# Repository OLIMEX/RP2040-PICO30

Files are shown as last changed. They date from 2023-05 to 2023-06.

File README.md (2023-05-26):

# RP2040-PICO30

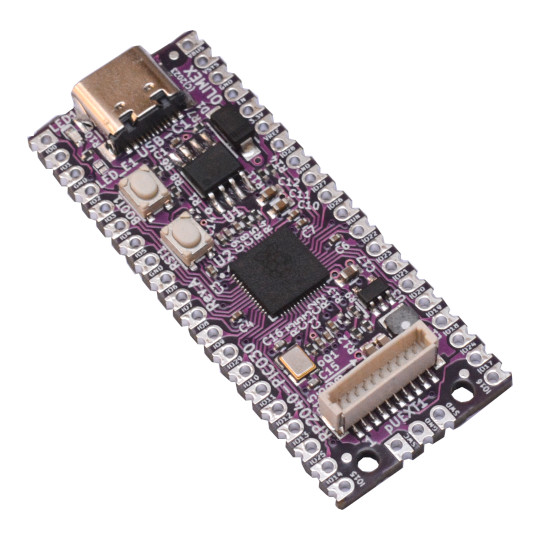
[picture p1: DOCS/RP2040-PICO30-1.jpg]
RP2040-PICO30-1


RP2040-PICO30 is Open Source Harrdware re-design of original RP2040-PICO from Rqaspberry Pi 

## Features

* RP2040 CortexM0 microcontroller
* RP2040-PICO pinout and dimentions
* SY8089A 3.3V 2A (3A peak) DCDC power supply
* 30 GPIOs available to the user
* USB-C High Speed USB 2.0 connector for powering the board and communication
* Boot button
* RESET button
* 2MB or 16MB Flash
* Optional UEXT connector (U version)
* Optional status LED (U version)
* Dimensions 51 x 21 mm

Product page: https://www.olimex.com/Products/MicroPython/RP2040-PICO30/open-source-hardware

## Licenses

* Hardware is released under CERN Open Hardware Licence Version 2 - Strongly Reciprocal, all silkscreen credits to Olimex should remain;
* Software is released under GPL3 Licensee
* Documentation is released under CC BY-SA 3.0

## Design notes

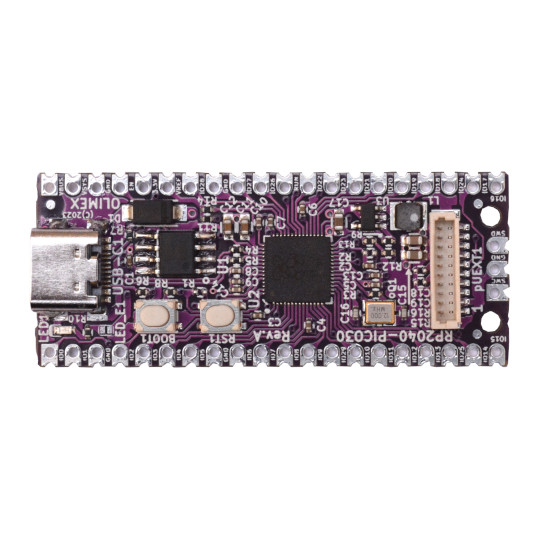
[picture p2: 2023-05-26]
DOCS/RP2040-PICO30-2.jpg

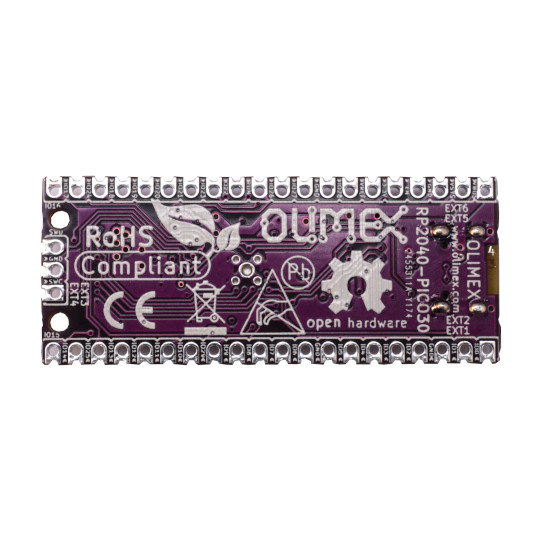
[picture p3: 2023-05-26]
DOCS/RP2040-PICO30-3.jpg

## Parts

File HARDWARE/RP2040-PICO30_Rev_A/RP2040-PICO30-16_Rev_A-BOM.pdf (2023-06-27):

# RP2040-PICO30-16_Rev_A-BOM 06/27/2023

Quantity | Designation | Package | Designator
1 | 1.3R/1%/R0402 | R0402 | R14
2 | 27R/R0402 | R0402 | R4,R5
2 | 100R/R0402 | R0402 | R3,R8
1 | 200R/1%/R0402 | R0402 | R11
2 | 5.1k/R0402 | R0402 | R6,R7
1 | 10k/R0402 | R0402 | R1
1 | 49.9k/1%/R0402 | R0402 | R13
1 | 220k/R0402 | R0402 | R12
1 | 1M/R0402 | R0402 | R9
1 | 2.2uH/1.5A/DCR=58mR/20% /3.00x3.00x1.50mm/ CD32(NRS3015T2R2MNGH) | CD32 | L1
2 | 27pF/50V/5%/C0G/C0402 | C0402 | C15,C16
12 | 100nF/10V/10%/X7R/C0402 | C0402 | C1,C2,C3,C4,C5, C6,C7,C8,C9, C10,C13,C14
2 | 1uF/10V/20%/X5R/C0603 | C0603 | C11,C12
3 | 22uF/6.3V/20%/X5R/C0603 | C0603 | C17,C18,C19
1 | 1N5822/SS34/SMA | SMA | D1
1 | W25Q128JVSIQ(SOIC-8_208mils) | SO-8_208mil | U1
1 | RP2040(QFN-56_7x7mm_P0.4mm) | QFN56 | U2
1 | SY8089AAAC(SOT23-5) | SOT-23-5 | U3
1 | Q12MHz/20pF/10ppm/4P/3.2x2.5mm | TSX-3.2x2.5mm | Q1
2 | YTS-A016-X | YTS-A016-X | BOOT1,RST1
1 | USB-C-16P-F (A40-00119-A52-12) | USB2.0_TYPE-C (A40-00119-A52-12) | USB-C1
1 | Opened | SJ_1_SMALLER | LED_E1
3 | NA(2.2k/R0402) | R0402 | R10,R15,R16
1 | NA(10k/R0402) | R0402 | R2
1 | NA(LED/GREEN/0603) | LED_0603 | LED1
1 | NA(SH1.0-10P-180D) | BM10B-SRSS-TB | pUEXT1
2 | NA(HN1x3) | HN1x3 | EXT3,EXT4
4 | NA(HN1x20) | HN1x20 | EXT1,EXT2, EXT5,EXT6

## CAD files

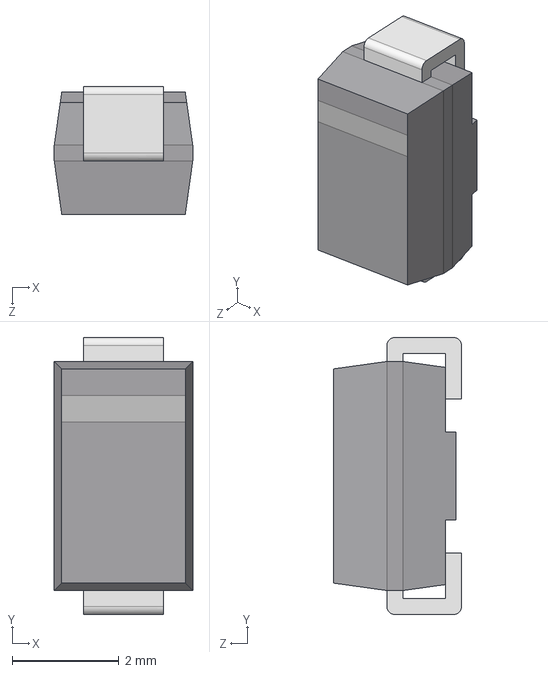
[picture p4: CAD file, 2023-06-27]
HARDWARE/RP2040-PICO30_Rev_A/3d/DO-214AC_SMA.step
2.60 x 5.20 x 2.40 mm

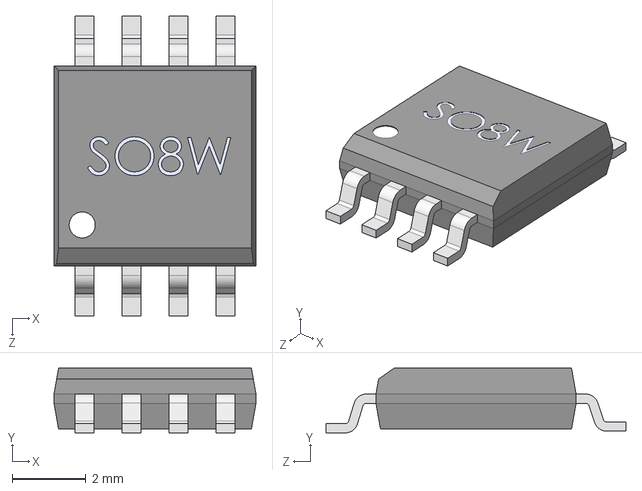
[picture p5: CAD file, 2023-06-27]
HARDWARE/RP2040-PICO30_Rev_A/3d/SO-8_208mil---SOIC8_Wide_5mmx5mm.step
5.46 x 1.75 x 8.10 mm

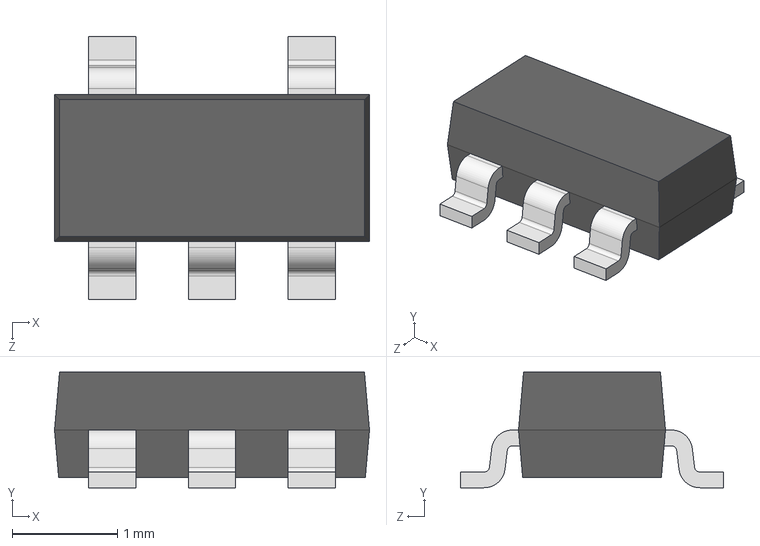
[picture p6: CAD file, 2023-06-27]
HARDWARE/RP2040-PICO30_Rev_A/3d/SOT-23-5.step
3.00 x 1.10 x 2.50 mm

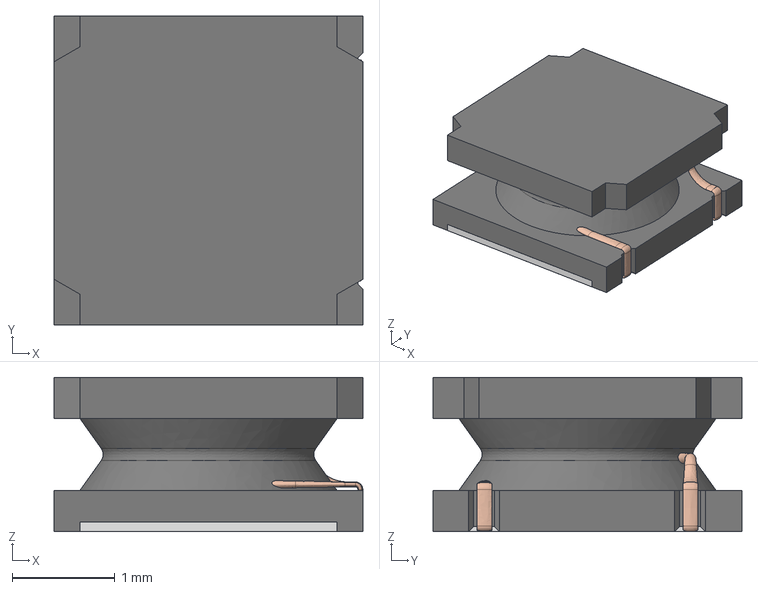
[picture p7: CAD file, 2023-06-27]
HARDWARE/RP2040-PICO30_Rev_A/3d/L-CD32_shielded.step
3.00 x 3.00 x 1.50 mm

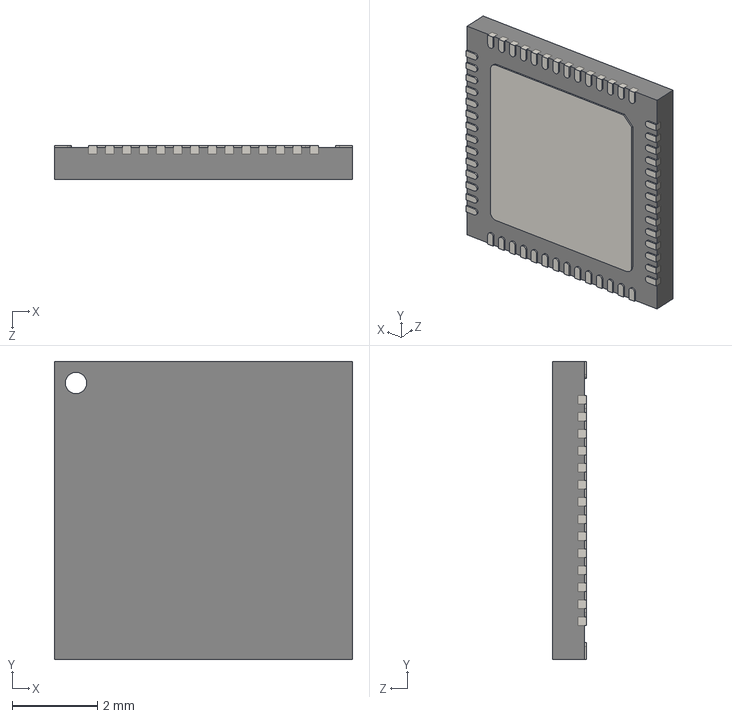
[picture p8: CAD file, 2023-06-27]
HARDWARE/RP2040-PICO30_Rev_A/3d/QFN56_0_4.step
7.00 x 7.00 x 0.8 mm

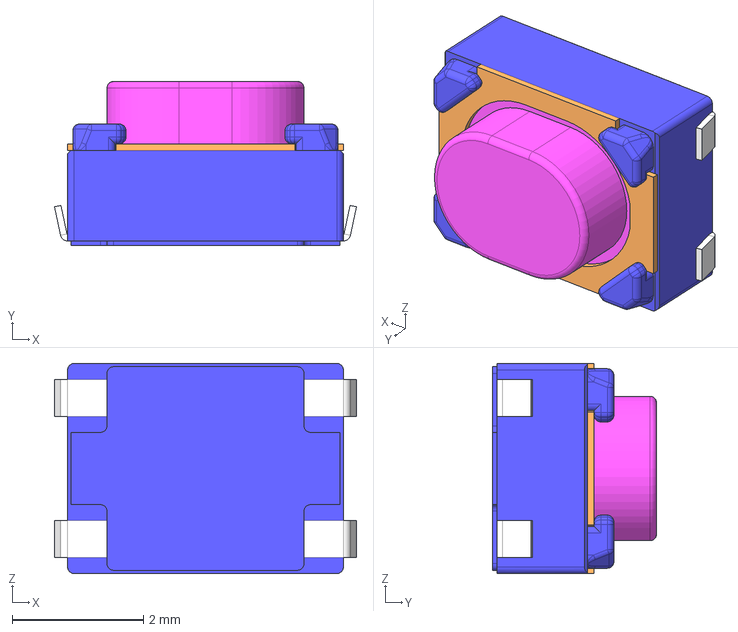
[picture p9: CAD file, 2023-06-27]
HARDWARE/RP2040-PICO30_Rev_A/3d/YTS-A016-X(SKRPABE010).stp
4.60 x 2.50 x 3.20 mm

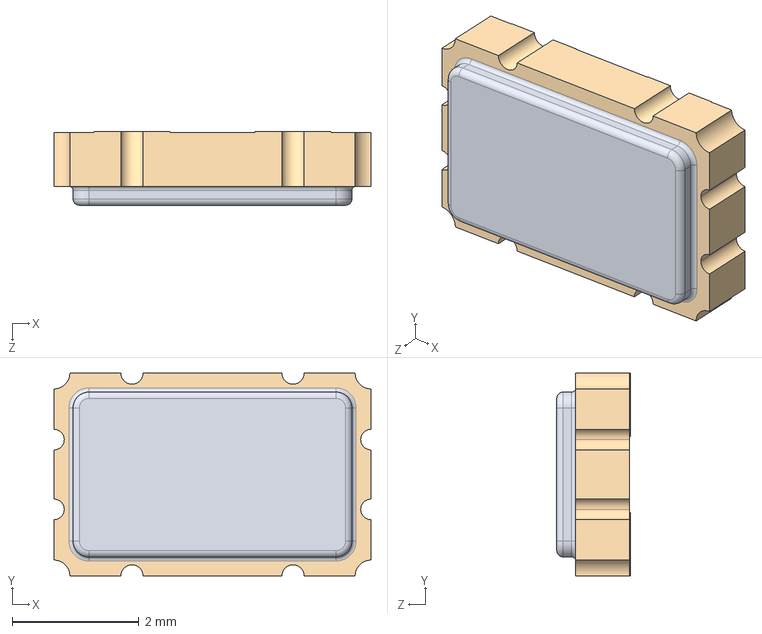
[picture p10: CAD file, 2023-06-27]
HARDWARE/RP2040-PICO30_Rev_A/3d/QSG5032.step
5.00 x 3.20 x 1.16 mm

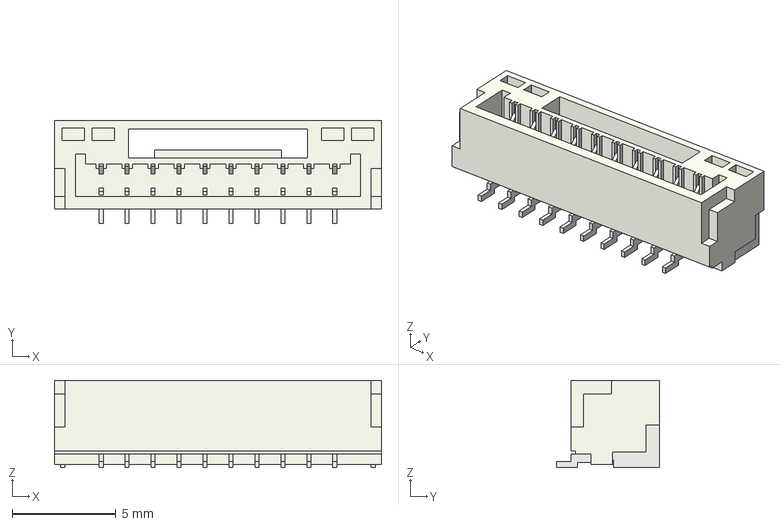
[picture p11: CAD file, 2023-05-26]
HARDWARE/RP2040-PICO30_Rev_A/3d/BM10B-SRSS-TB(JST_GH_BM10B-GHS-TBT_1x10-1MP_P1.25mm_Vertical).step
15.8 x 4.95 x 4.20 mm

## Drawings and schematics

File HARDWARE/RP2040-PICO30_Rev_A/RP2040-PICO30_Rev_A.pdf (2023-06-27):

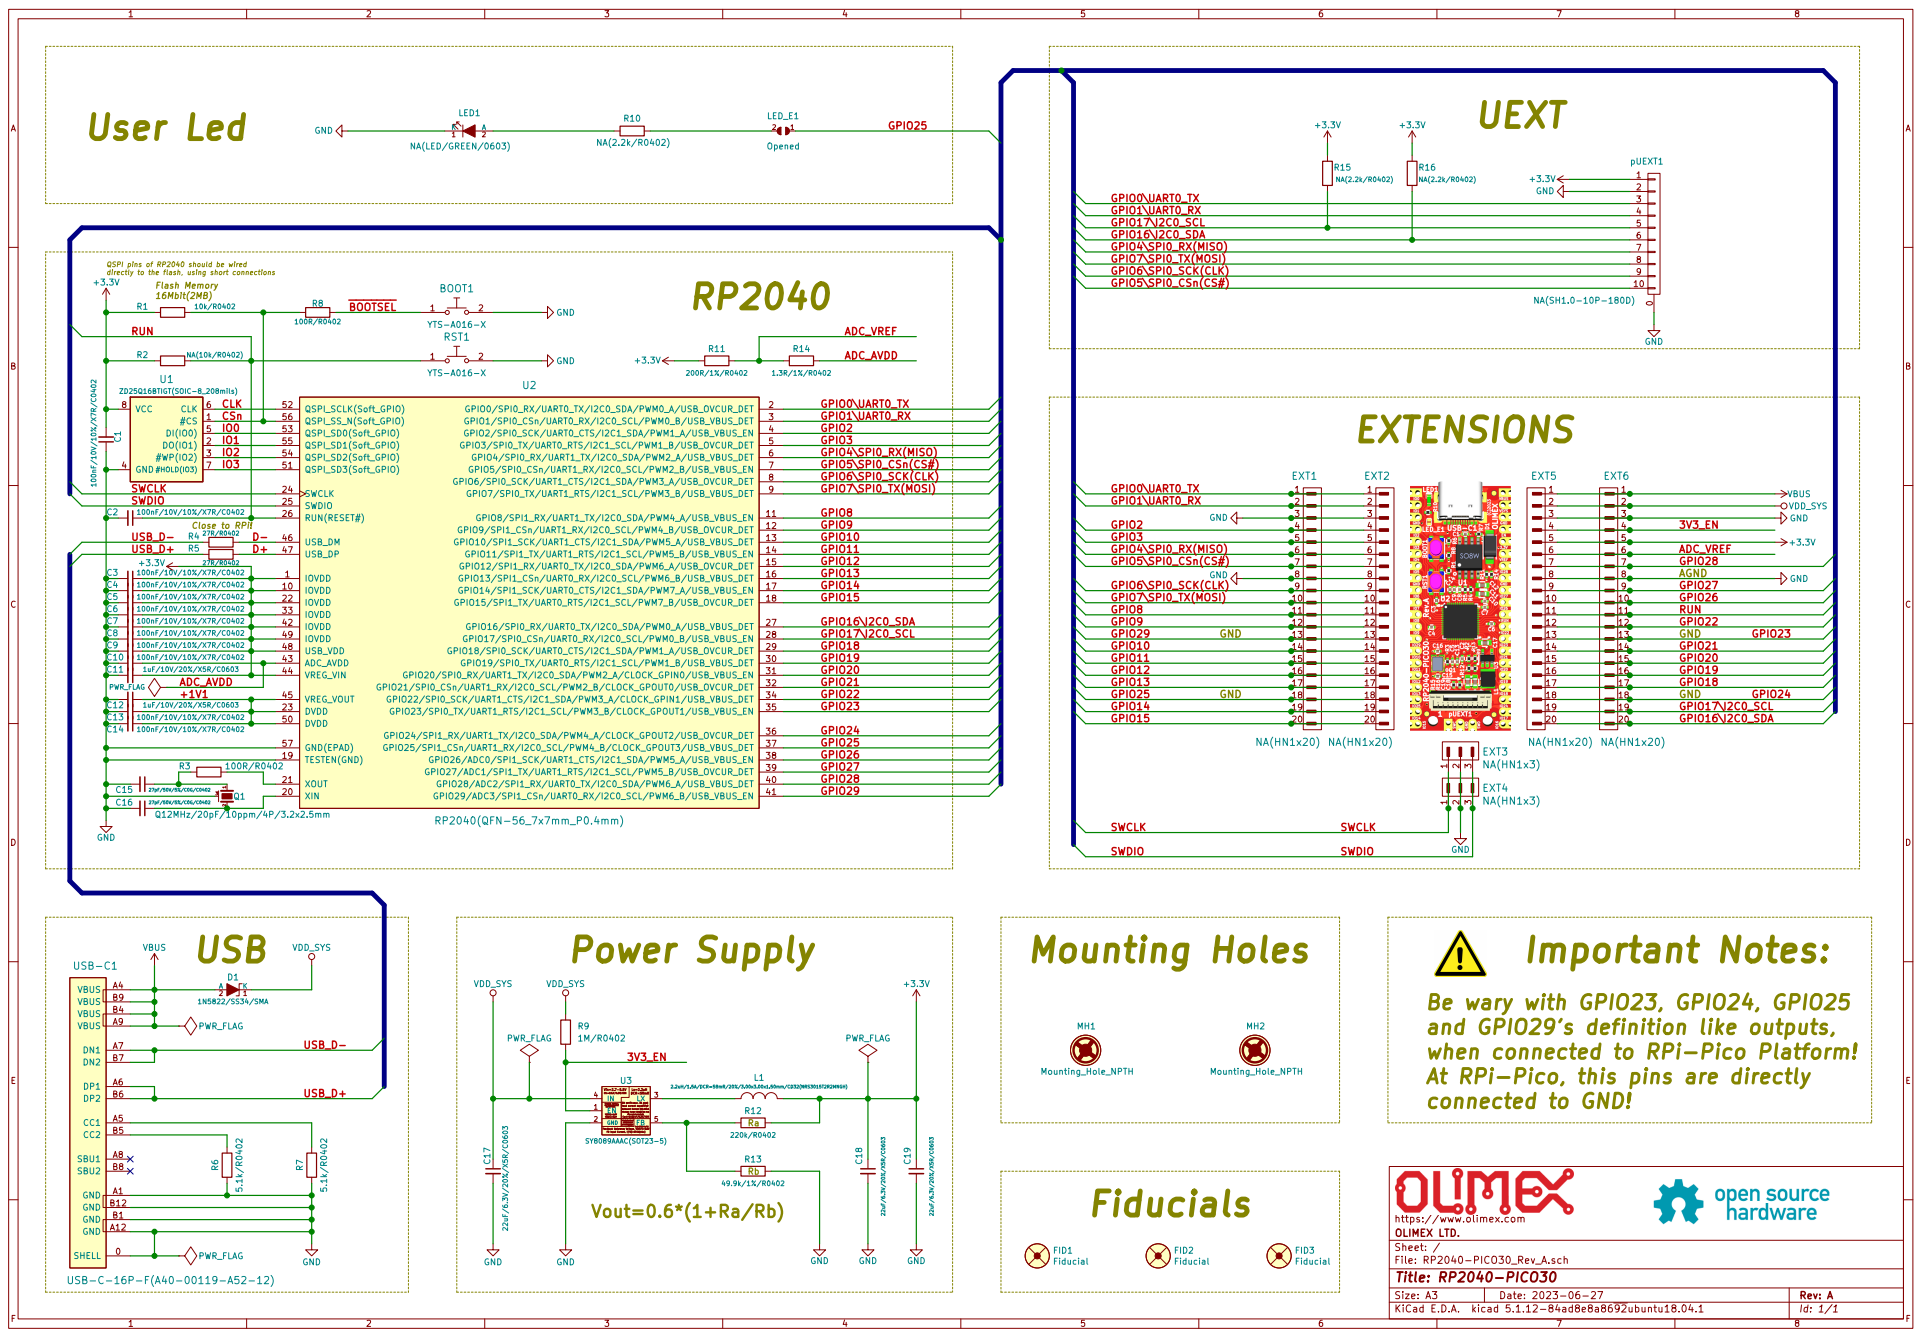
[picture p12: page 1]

and GPIO29's definition like outputs,
when connected to RPi-Pico Platform!
At RPi-Pico, this pins are directly
connected to GND!

load current capability! Lx=2.2uH

Do not float. Enable control. FB Input Current, I(FB)=50nA(max) Feedback Reference Voltage, V(REF)=0.6V

File: RP2040-PICO30_Rev_A.sch Sheet: / OLIMEX LTD. https://www.olimex.com

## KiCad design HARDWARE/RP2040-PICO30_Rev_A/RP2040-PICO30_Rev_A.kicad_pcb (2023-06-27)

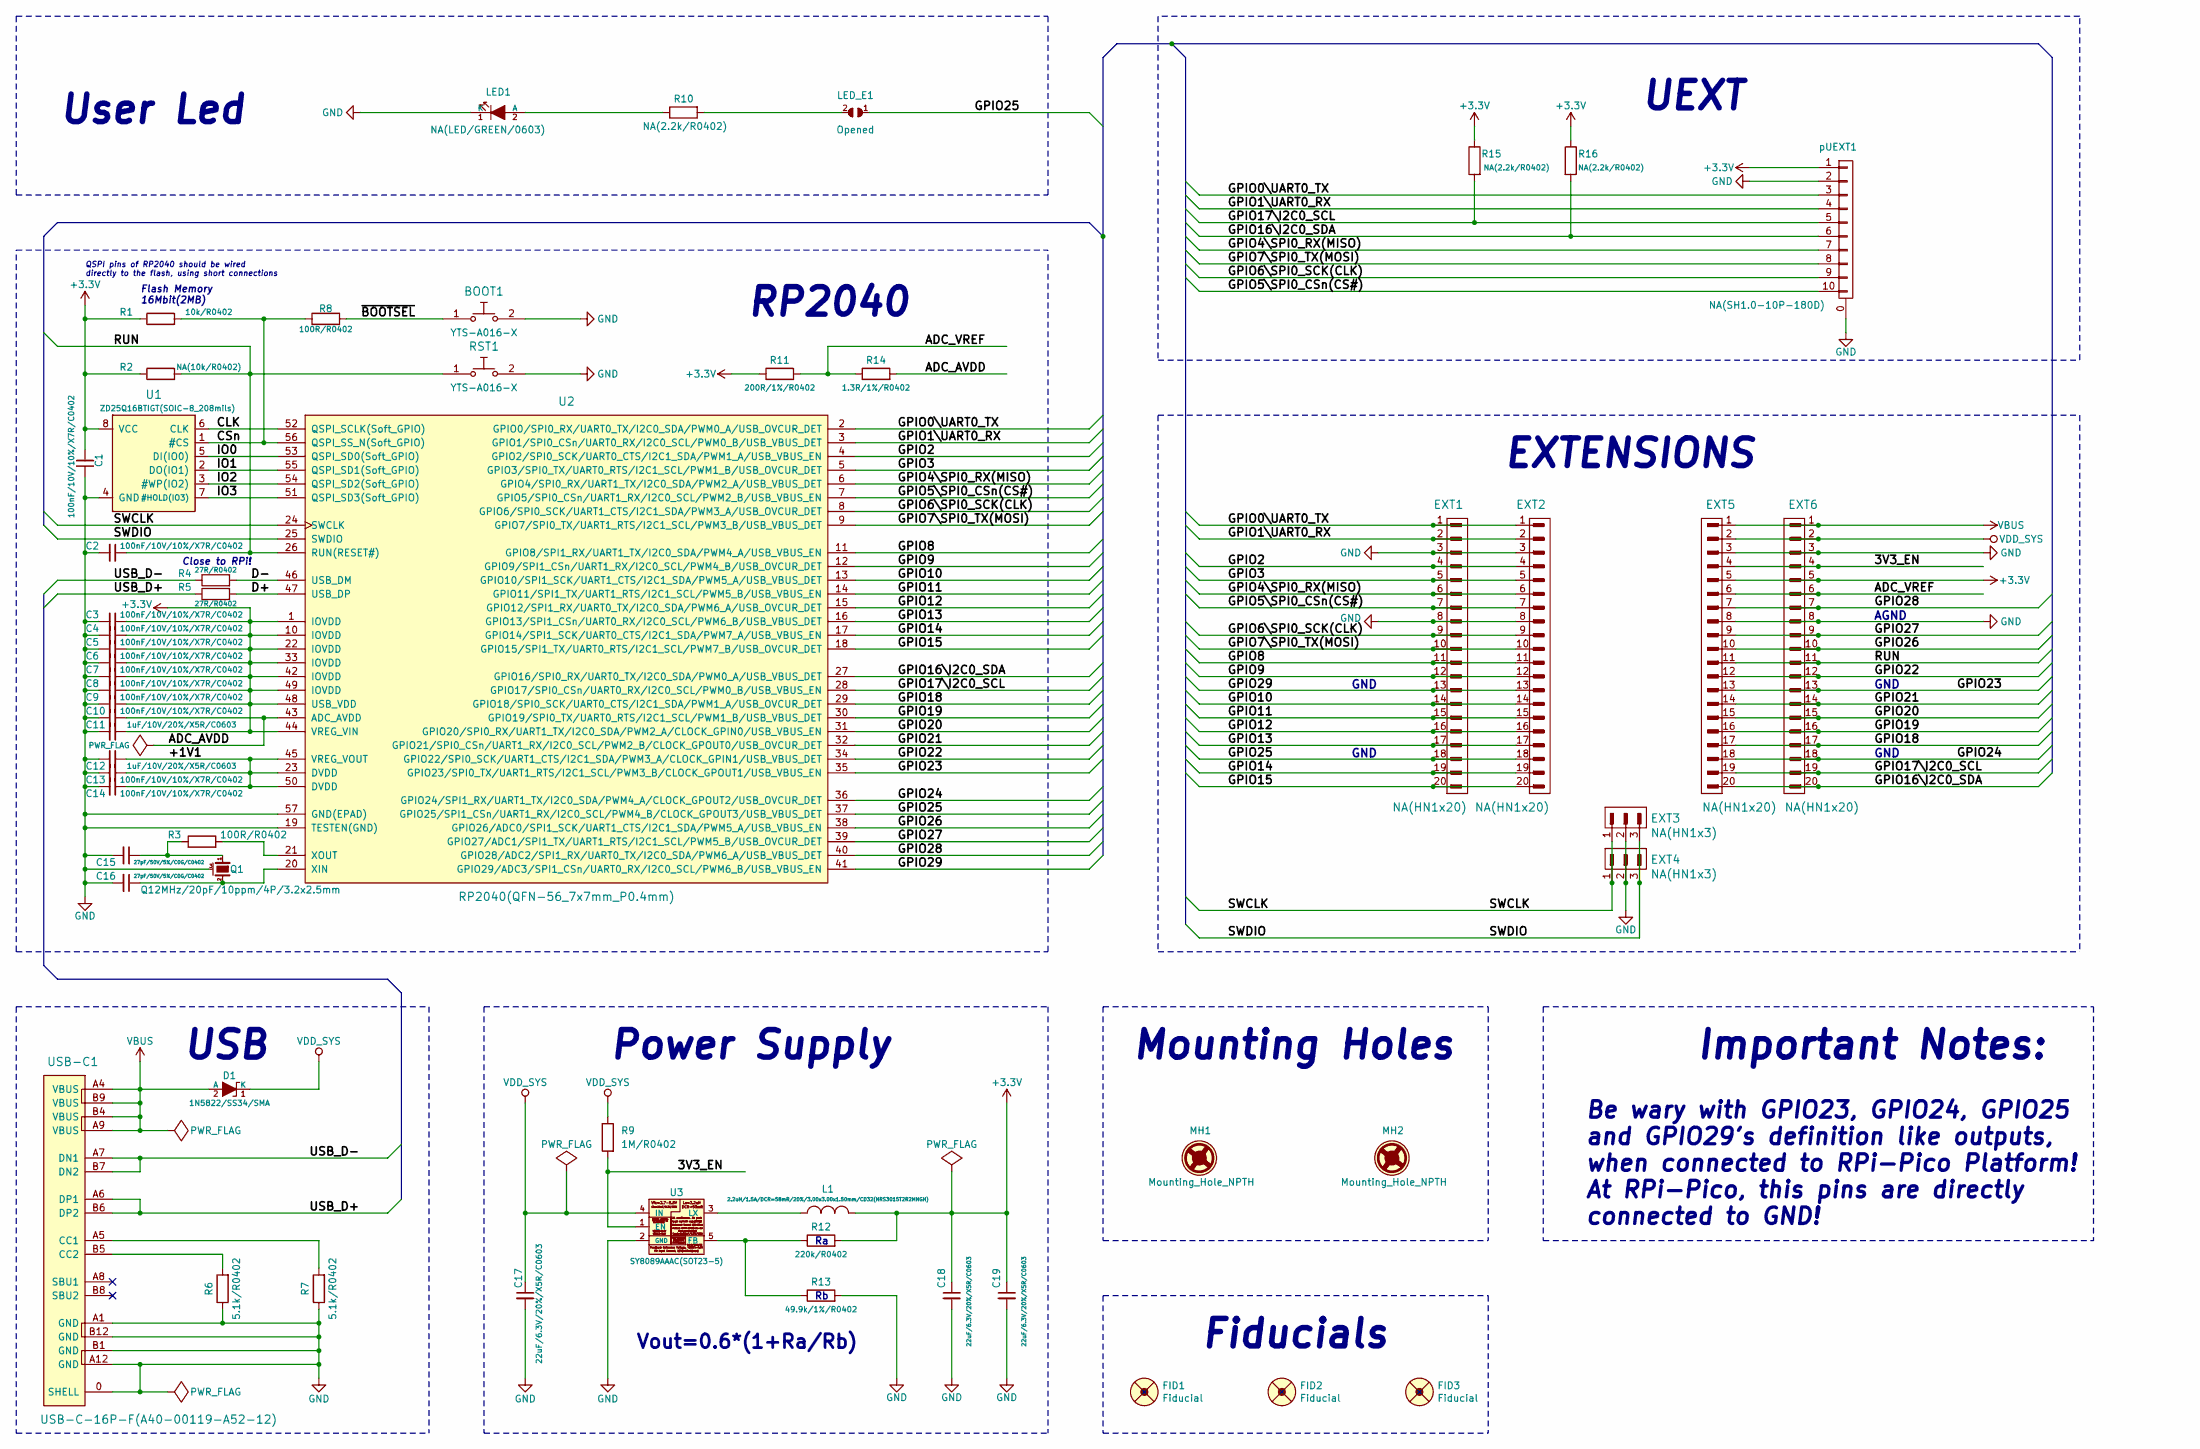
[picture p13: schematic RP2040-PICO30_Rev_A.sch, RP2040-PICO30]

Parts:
BOOT1: YTS-A016-X
C1, C2, C3, C4, C5, C6, C7, C8, C9, C10, C13, C14: 100nF/10V/10%/X7R/C0402; C_0402_5MIL_DWS
C11, C12: 1uF/10V/20%/X5R/C0603; C_0603_5MIL_DWS
C15, C16: 27pF/50V/5%/C0G/C0402; C_0402_5MIL_DWS
C17, C18, C19: 22uF/6.3V/20%/X5R/C0603; C_0603_5MIL_DWS
D1: 1N5822/SS34/SMA; SMA-KA
EXT1, EXT2, EXT5, EXT6: NA(HN1x20); HN1x20
EXT3, EXT4: NA(HN1x3); HN1x3
FID1, FID2, FID3: Fiducial; Fiducial1x3
L1: 2.2uH/1.5A/DCR=58mR/20%/3.00x3.00x1.50mm/CD32(NRS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; CD32
LED1: NA(LED/GREEN/0603); LED_0603_KA
LED_E1: Opened; SJ_1_SMALLER
MH1, MH2: Mounting_Hole_NPTH; Mounting_Hole_Drill-2.1mm_Clerance-4mm
Q1: Q12MHz/20pF/10ppm/4P/3.2x2.5mm; TSX-3.2x2.5mm_GND(3)
R1: 10k/R0402; R_0402_5MIL_DWS
R2: NA(10k/R0402); R_0402_5MIL_DWS
R3, R8: 100R/R0402; R_0402_5MIL_DWS
R4, R5: 27R/R0402; R_0402_5MIL_DWS
R6, R7: 5.1k/R0402; R_0402_5MIL_DWS
R9: 1M/R0402; R_0402_5MIL_DWS
R10, R15, R16: NA(2.2k/R0402); R_0402_5MIL_DWS
R11: 200R/1%/R0402; R_0402_5MIL_DWS
R12: 220k/R0402; R_0402_5MIL_DWS
R13: 49.9k/1%/R0402; R_0402_5MIL_DWS
R14: 1.3R/1%/R0402; R_0402_5MIL_DWS
RST1: YTS-A016-X
U1: ZD25Q16BTIGT(SOIC-8_208mils); SO-8_208mil
U2: RP2040(QFN-56_7x7mm_P0.4mm); QFN56_7x7_Pitch_0.4mm
U3: SY8089AAAC(SOT23-5); SOT-23-5
USB-C1: USB-C-16P-F(A40-00119-A52-12); USB2.0_TYPE-C(A40-00119-A52-12)
pUEXT1: NA(SH1.0-10P-180D); BM10B-SRSS-TB

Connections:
+3.3V: C1.2, C3.1, C4.1, C5.1, C6.1, C7.1, C8.1, C9.1, C11.1, C18.1, C19.1, EXT5.5, EXT6.5, L1.2, R1.1, R2.1, R11.1, R12.2, R15.1, R16.1, U1.8 (VCC), U2.1 (IOVDD), U2.10 (IOVDD), U2.22 (IOVDD), U2.33 (IOVDD), U2.42 (IOVDD), U2.44 (VREG_VIN), U2.48 (USB_VDD), U2.49 (IOVDD), pUEXT1.1
/3V3_EN: EXT5.4, EXT6.4, R9.2, U3.1 (EN)
/+1V1: C12.1, C13.1, C14.1, U2.23 (DVDD), U2.45 (VREG_VOUT), U2.50 (DVDD)
/ADC_AVDD: C10.1, R14.2, U2.43 (ADC_AVDD)
/ADC_VREF: EXT5.6, EXT6.6, R11.2, R14.1
/CLK: U1.6 (CLK), U2.52 (QSPI_SCLK(Soft_GPIO))
/CSn: R1.2, R8.1, U1.1 (#CS), U2.56 (QSPI_SS_N(Soft_GPIO))
/D+: R5.2, U2.47 (USB_DP)
/D-: R4.2, U2.46 (USB_DM)
/GPIO0\UART0_TX: EXT1.1, EXT2.1, U2.2 (GPIO0/SPI0_RX/UART0_TX/I2C0_SDA/PWM0_A/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), pUEXT1.3
/GPIO1\UART0_RX: EXT1.2, EXT2.2, U2.3 (GPIO1/SPI0_CSn/UART0_RX/I2C0_SCL/PWM0_B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), pUEXT1.4
/GPIO2: EXT1.4, EXT2.4, U2.4 (GPIO2/SPI0_SCK/UART0_CTS/I2C1_SDA/PWM1_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)
/GPIO3: EXT1.5, EXT2.5, U2.5 (GPIO3/SPI0_TX/UART0_RTS/I2C1_SCL/PWM1_B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)
/GPIO4\SPI0_RX(MISO): EXT1.6, EXT2.6, U2.6 (GPIO4/SPI0_RX/UART1_TX/I2C0_SDA/PWM2_A/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), pUEXT1.7
/GPIO5\SPI0_CSn(CS#): EXT1.7, EXT2.7, U2.7 (GPIO5/SPI0_CSn/UART1_RX/I2C0_SCL/PWM2_B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), pUEXT1.10
/GPIO6\SPI0_SCK(CLK): EXT1.9, EXT2.9, U2.8 (GPIO6/SPI0_SCK/UART1_CTS/I2C1_SDA/PWM3_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), pUEXT1.9
/GPIO7\SPI0_TX(MOSI): EXT1.10, EXT2.10, U2.9 (GPIO7/SPI0_TX/UART1_RTS/I2C1_SCL/PWM3_B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), pUEXT1.8
/GPIO8: EXT1.11, EXT2.11, U2.11 (GPIO8/SPI1_RX/UART1_TX/I2C0_SDA/PWM4_A/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)
/GPIO9: EXT1.12, EXT2.12, U2.12 (GPIO9/SPI1_CSn/UART1_RX/I2C0_SCL/PWM4_B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)
/GPIO10: EXT1.14, EXT2.14, U2.13 (GPIO10/SPI1_SCK/UART1_CTS/I2C1_SDA/PWM5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)
/GPIO11: EXT1.15, EXT2.15, U2.14 (GPIO11/SPI1_TX/UART1_RTS/I2C1_SCL/PWM5_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)
/GPIO12: EXT1.16, EXT2.16, U2.15 (GPIO12/SPI1_RX/UART0_TX/I2C0_SDA/PWM6_A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)
/GPIO13: EXT1.17, EXT2.17, U2.16 (GPIO13/SPI1_CSn/UART0_RX/I2C0_SCL/PWM6_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)
/GPIO14: EXT1.19, EXT2.19, U2.17 (GPIO14/SPI1_SCK/UART0_CTS/I2C1_SDA/PWM7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)
/GPIO15: EXT1.20, EXT2.20, U2.18 (GPIO15/SPI1_TX/UART0_RTS/I2C1_SCL/PWM7_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)
/GPIO16\I2C0_SDA: EXT5.20, EXT6.20, R16.2, U2.27 (GPIO16/SPI0_RX/UART0_TX/I2C0_SDA/PWM0_A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), pUEXT1.6
/GPIO17\I2C0_SCL: EXT5.19, EXT6.19, R15.2, U2.28 (GPIO17/SPI0_CSn/UART0_RX/I2C0_SCL/PWM0_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), pUEXT1.5
/GPIO18: EXT5.17, EXT6.17, U2.29 (GPIO18/SPI0_SCK/UART0_CTS/I2C1_SDA/PWM1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)
/GPIO19: EXT5.16, EXT6.16, U2.30 (GPIO19/SPI0_TX/UART0_RTS/I2C1_SCL/PWM1_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)
/GPIO20: EXT5.15, EXT6.15, U2.31 (GPIO20/SPI0_RX/UART1_TX/I2C0_SDA/PWM2_A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)
/GPIO21: EXT5.14, EXT6.14, U2.32 (GPIO21/SPI0_CSn/UART1_RX/I2C0_SCL/PWM2_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)
/GPIO22: EXT5.12, EXT6.12, U2.34 (GPIO22/SPI0_SCK/UART1_CTS/I2C1_SDA/PWM3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)
/GPIO23: EXT5.13, EXT6.13, U2.35 (GPIO23/SPI0_TX/UART1_RTS/I2C1_SCL/PWM3_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)
/GPIO24: EXT5.18, EXT6.18, U2.36 (GPIO24/SPI1_RX/UART1_TX/I2C0_SDA/PWM4_A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)
/GPIO25: EXT1.18, EXT2.18, LED_E1.1, U2.37 (GPIO25/SPI1_CSn/UART1_RX/I2C0_SCL/PWM4_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)
/GPIO26: EXT5.10, EXT6.10, U2.38 (GPIO26/ADC0/SPI1_SCK/UART1_CTS/I2C1_SDA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)
/GPIO27: EXT5.9, EXT6.9, U2.39 (GPIO27/ADC1/SPI1_TX/UART1_RTS/I2C1_SCL/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)
/GPIO28: EXT5.7, EXT6.7, U2.40 (GPIO28/ADC2/SPI1_RX/UART0_TX/I2C0_SDA/P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)
/GPIO29: EXT1.13, EXT2.13, U2.41 (GPIO29/ADC3/SPI1_CSn/UART0_RX/I2C0_SCL/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)
/IO0: U1.5 (DI(IO0)), U2.53 (QSPI_SD0(Soft_GPIO))
/IO1: U1.2 (DO(IO1)), U2.55 (QSPI_SD1(Soft_GPIO))
/IO2: U1.3 (#WP(IO2)), U2.54 (QSPI_SD2(Soft_GPIO))
/IO3: U1.7 (#HOLD(IO3)), U2.51 (QSPI_SD3(Soft_GPIO))
/RUN: C2.1, EXT5.11, EXT6.11, R2.2, RST1.1, U2.26 (RUN(RESET#))
/SWCLK: EXT3.1, EXT4.1, U2.24 (SWCLK)
/SWDIO: EXT3.3, EXT4.3, U2.25 (SWDIO)
/USB_D+: R5.1, USB-C1.A6 (DP1), USB-C1.B6 (DP2)
/USB_D-: R4.1, USB-C1.A7 (DN1), USB-C1.B7 (DN2)
/~BOOTSEL: BOOT1.1, R8.2
GND: BOOT1.2, C1.1, C2.2, C3.2, C4.2, C5.2, C6.2, C7.2, C8.2, C9.2, C10.2, C11.2, C12.2, C13.2, C14.2, C15.2, C16.2, C17.2, C18.2, C19.2, EXT1.3, EXT1.8, EXT2.3, EXT2.8, EXT3.2, EXT4.2, EXT5.3, EXT5.8, EXT6.3, EXT6.8, LED1.1 (K), Q1.3 (case), R6.1, R7.1, R13.2, RST1.2, U1.4 (GND), U2.19 (TESTEN(GND)), U2.57 (GND(EPAD)), U3.2 (GND), USB-C1.0 (SHELL), USB-C1.A1 (GND), USB-C1.A12 (GND), USB-C1.B1 (GND), USB-C1.B12 (GND), pUEXT1.0, pUEXT1.2
unnamed: C15.1, Q1.1, R3.1
unnamed: C16.1, Q1.2, U2.20 (XIN)
unnamed: L1.1, U3.3 (LX)
unnamed: LED1.2 (A), R10.1
unnamed: LED_E1.2, R10.2
unnamed: R3.2, U2.21 (XOUT)
unnamed: R6.2, USB-C1.B5 (CC2)
unnamed: R7.2, USB-C1.A5 (CC1)
unnamed: R12.1, R13.1, U3.5 (FB)
VBUS: D1.2 (A), EXT5.1, EXT6.1, USB-C1.A4 (VBUS), USB-C1.A9 (VBUS), USB-C1.B4 (VBUS), USB-C1.B9 (VBUS)
VDD_SYS: C17.1, D1.1 (K), EXT5.2, EXT6.2, R9.1, U3.4 (IN)

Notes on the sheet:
Fiducials
Mounting Holes
Power Supply
Vout=0.6*(1+Ra/Rb)
UEXT
Flash Memory 16Mbit(2MB)
Close to RPi!
QSPI pins of RP2040 should be wired directly to the flash, using short connections
EXTENSIONS
USB
User Led
RP2040
AGND
GND
Important Notes:
Be wary with GPIO23, GPIO24, GPIO25 and GPIO29's definition like outputs, when connected to RPi-Pico Platform! At RPi-Pico, this pins are directly connected to GND!

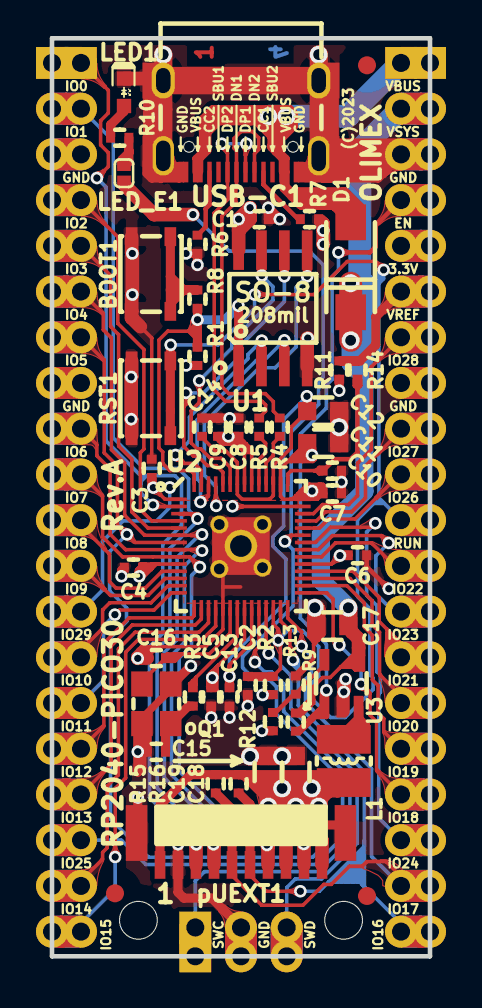
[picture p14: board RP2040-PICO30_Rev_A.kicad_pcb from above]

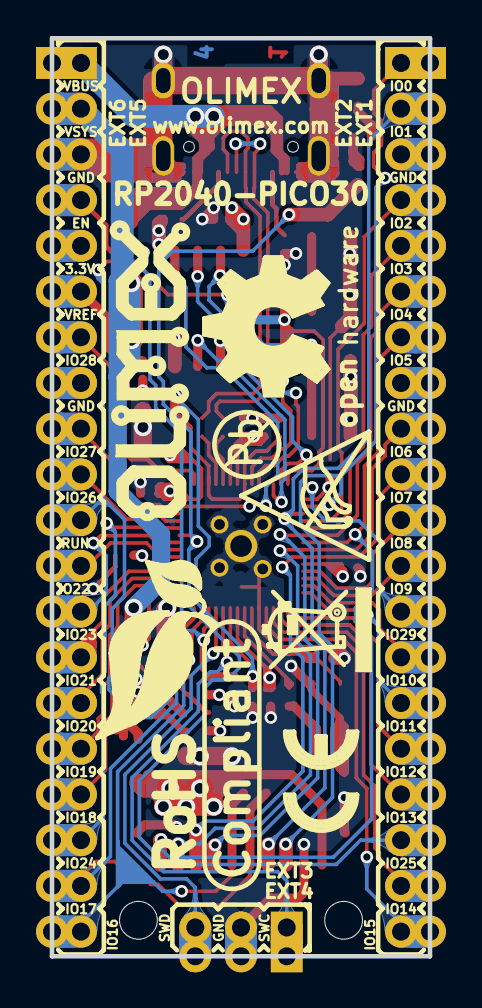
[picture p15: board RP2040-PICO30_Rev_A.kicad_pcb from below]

Board: 4 copper layers, 21.0 x 51.0 mm, 65 parts (13 on the bottom side), 61 nets.

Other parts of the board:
Logo_OLIMEX_TB-Bottom: Logo_OLIMEX_TB
Sign_Antistatic: Sign_Antistatic
Sign_CE: CE_Sign
Sign_OSHW_8x8: Sign_OSHW_8x8
Sign_PB-Free: Sign_PB-Free
Sign_RecycleBin: Sign_RecycleBin; Sign_RecycleBin_1
Sign_RoHS: Sign_RoHS; Sign_RoHS_1

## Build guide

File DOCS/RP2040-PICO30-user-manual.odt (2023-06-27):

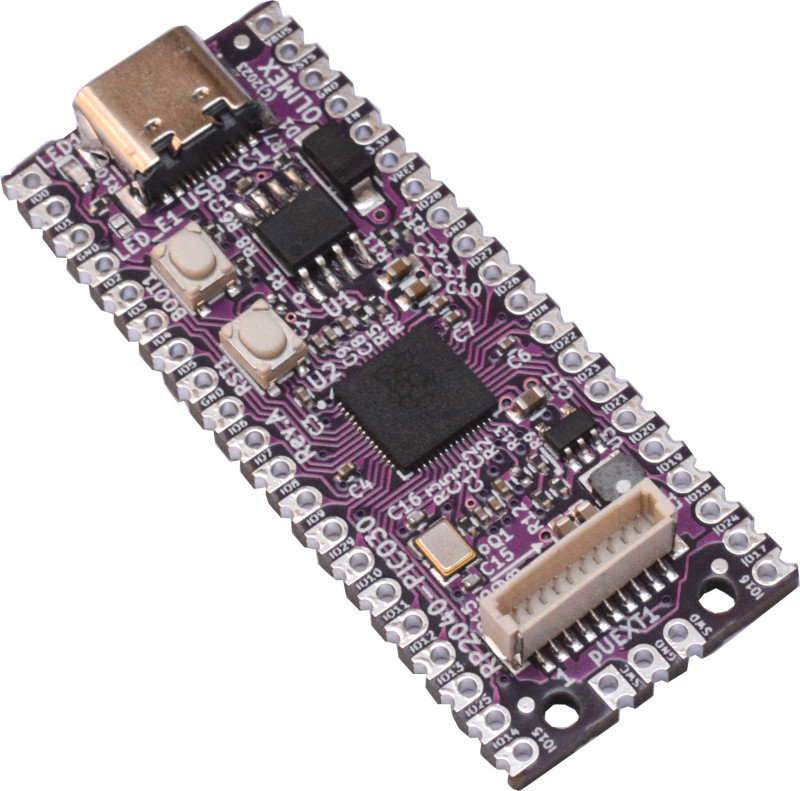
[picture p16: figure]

RP2040-PICO30

User Manual

Rev.1.1 June 2023 www.olimex.com

# Introduction to RP2040-PICO30

RP2040-PICO30 is a re-design of the popular Raspberry Pi Pico (with RP2040) board with these improvements:

- All 30 of RP2040 GPIOs are available to the user
- USB-C power supply connector which allows more current to be used by the board
- SY8089A 3.3V 2A (3A peak) DCDC power supply
- 2MB or 16MB Flash versions are possible
- RESET button added
- Four layer board for better noise immunity and USB differential pair routing
- UEXT connector (pUEXT 1.0 mm step connector)
- Dimensions: 21 x 51 mm

RP2040-PICO30 keeps same layout and pinout as the original Raspberry Pi Pico (RP204), however the four extra GPIOs are placed on locations that are GNDs in the original design (original deisgn has 8 GNDs on the headers, while RP2040-PICO30 has 4 GNDs exposed).

The original RP2040-PICO exposes only 26 out of the 30 RP2040 GPIOs and RP2040-PICO30 solves this issue.

+ Important notice: RP2040-PICO30 keeps the same layout as Raspberry Pi Pico, however in order to expose the 4 extra GPIOs, we sacrfice 4 of the GNDs (that are exposed in the original design). RP2040-PICO30 adds the four missing GPIOs: GPIO23, GPIO24, GPIO25, GPIO29 on four of the eight GND pads. When you use RP2040-PICO30 on RPi Pico board make sure these GPIOs are INPUTS!

## Order codes for RP2040-PICO30 and accessories:

RP2040-PICO30 (https://www.olimex.com/Products/MicroPython/RP2040-PICO30/open-source-hardware) industrial grade RPi Pico (RP2040) with 30 GPIOs exposed

RP2040-PICO30U (https://www.olimex.com/Products/MicroPython/RP2040-PICO30U/open-source-hardware) RP2040-PICO30 with UEXT, LED, R10, R15, R16

RP2040-PICO30-16 (https://www.olimex.com/Products/MicroPython/RP2040-PICO30-16/open-source-hardware) RP2040-PICO30 with 16MB of Flash (max possible for RP2040)

RP2040-PICO30U-16 (https://www.olimex.com/Products/MicroPython/RP2040-PICO30U-16/open-source-hardware) RP2040-PICO30 with 16MB of Flash, UEXT, LED, R10, R15, R16

# HARDWARE

## RP2040-PICO30 hardware layout:

RP2040

UEXT connector with SPI I2C UART

PIN.40

PIN.21

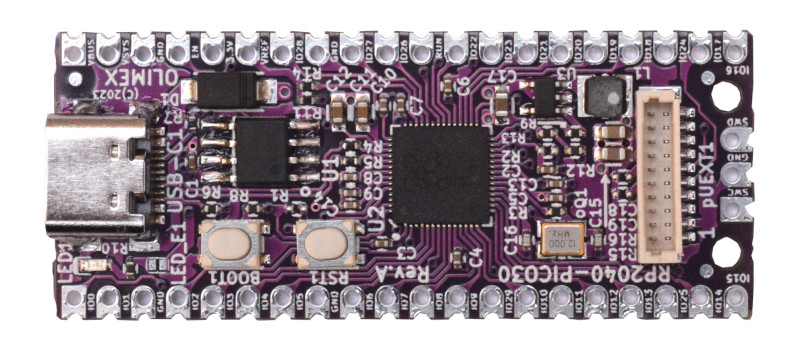
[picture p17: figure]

Flash

USB-C

DEBUG

LED

LED enable jumper

RESET button

PIN.20

Boot button

PIN.1

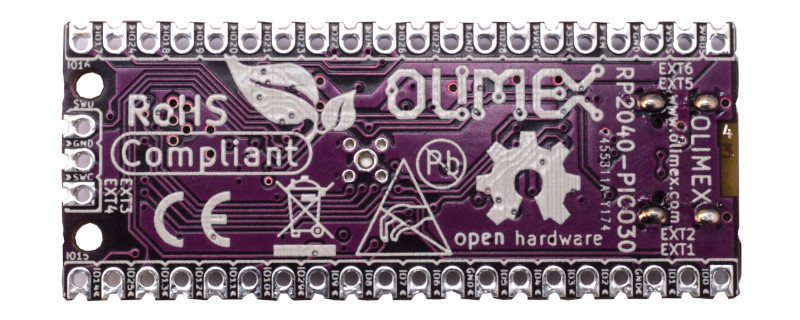
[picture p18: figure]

## RP2040-PICO30 GPIOs:

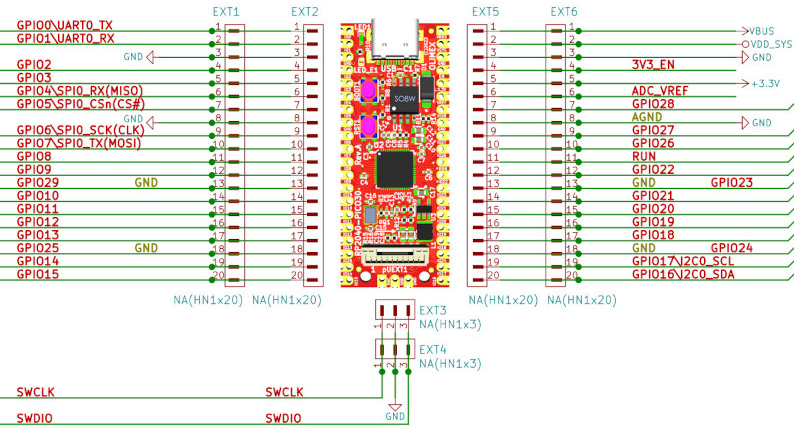
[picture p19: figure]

Table1. Notable pins
Power-related
VBUS | +5V line coming from USB-C, can be used as output
VDD_SYS | +5V line that can be used as output or input but if you want to use it as an input (to power the board from an external 5V source) make sure that the board is not powered (connected) to USB! Having power source connecting to USB and VDD_SYS simultaneously would lead to short-circuit and damage.
+3.3V | +3.3V line, can be used as output which can source up to 2A @ 3.3V
3V3_EN | Input, when pulled to GND stops the 3.3V DCDC converter
GPIO-related
GPIO23 (Pin #28 from the original RPi Pico layout) | This GPIO is not led out in the original RP2040-PICO design and on this place there is GND line so if you use RP2040-PICO30 in RP2040-PICO design make sure to initialize it as INPUT
GPIO24 (Pin #23 from the original RPi Pico layout) | This GPIO is not led out in the original RP2040-PICO design and on this place there is GND line so if you use RP2040-PICO30 in RP2040-PICO design make sure to initialize it as INPUT
GPIO25 (Pin #18 from the original RPi Pico layout) | This GPIO is not led out in the original RP2040-PICO design and on this place there is GND line so if you use RP2040-PICO30 in RP2040-PICO design make sure to initialize it as INPUT
GPIO29 (Pin #13 from the original RPi Pico layout) | This GPIO is not led out in the original RP2040-PICO design and on this place there is GND line so if you use RP2040-PICO30 in RP2040-PICO design make sure to initialize it as INPUT

Basically RPi Pico has 8 GNDs in total exposed on the connectors. While RP2040-PICO30 has 4GNDs and 4 extra GPIOs.

## RP2040-PICO30 schematics:

RP2040-PICO30 (https://www.olimex.com/Products/MicroPython/RP2040-PICO30/open-source-hardware) latest schematic is available at our GitHub (https://github.com/OLIMEX/RP2040-PICO30)

## UEXT connector:

UEXT connector stands for Universal EXTension connector and contains +3.3V, GND, I2C, SPI, UART signals.

UEXT connector can be in different shapes.

The original UEXT connector is 0.1” 2.54mm step boxed plastic connector. All signals are at 3.3V levels.

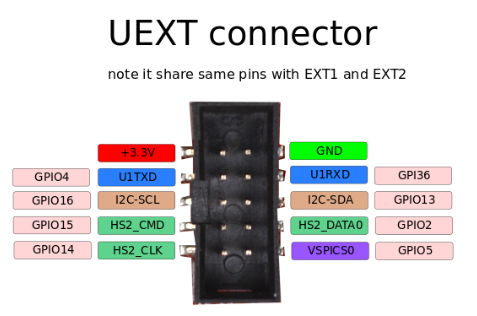
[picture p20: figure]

As the boards become smaller and smaller, we introduced smaller form-factor UEXT connectors too alongside the original UEXT connector:

- mUEXT is 1.27 mm step boxed header connector which is with same layout as UEXT;

- pUEXT is 1.0 mm single row connector (this is the connector used in RP2040-PICO30).

We are in process of releasing adapter that can be used to into connect devices with different type and size of UEXT connector.

Olimex manufactures a number of MODULES (https://www.olimex.com/Products/Modules/) compatible with this connector. There are temperature, humidity, pressure, magnetic field, light sensors. Modules with LCDs, LED matrix, relays, Bluetooth, Zigbee, WiFi, GSM, GPS, RFID, RTC, EKG, sensors, and more.

## pUEXT signals:

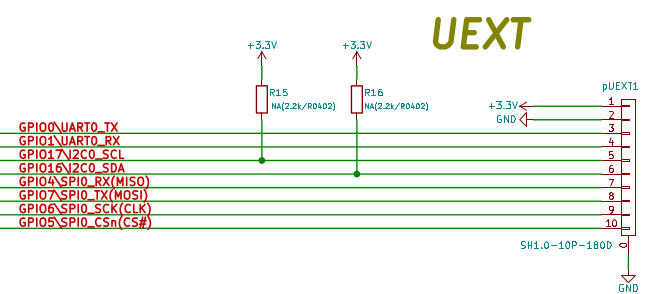
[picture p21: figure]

# SOFTWARE

RP2040-PICO30 uses the same software as RP2040-PICO:

- Raspberry PI C-SDK
- MicroPython SDK

# DOCUMENT REVISION HISTORY

Document revision 1.1 June 2023

- product names fixes

- general improvements

Document revision 1.0 May 2023

- initial release

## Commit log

2023-05-26 initial update
    [BM10B-SRSS-TB(JST_GH_BM10B-GHS-TBT_1x10-1MP_P1.25mm_Vertical).step, DO-214AC_SMA.step, L-CD32_shielded.step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]
2023-06-27 Update
    Improved design files
    [BM10B-SRSS-TB(JST_GH_BM10B-GHS-TBT_1x10-1MP_P1.25mm_Vertical).step, DO-214AC_SMA.step, L-CD32_shielded.step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]

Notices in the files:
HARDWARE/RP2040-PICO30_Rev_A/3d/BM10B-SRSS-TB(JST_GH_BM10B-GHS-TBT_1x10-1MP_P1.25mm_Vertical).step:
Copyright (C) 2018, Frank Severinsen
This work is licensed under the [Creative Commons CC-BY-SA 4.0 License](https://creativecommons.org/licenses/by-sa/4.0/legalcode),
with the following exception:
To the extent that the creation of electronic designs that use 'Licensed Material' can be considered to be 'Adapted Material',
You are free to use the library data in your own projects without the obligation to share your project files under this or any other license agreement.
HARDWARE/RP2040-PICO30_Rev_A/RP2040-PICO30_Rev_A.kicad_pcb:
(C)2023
